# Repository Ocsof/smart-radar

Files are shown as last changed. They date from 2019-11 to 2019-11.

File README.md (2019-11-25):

This is an embedded system implementing a smart radar for seeking and tracking objects.

It's made of a sonar S mounted on a servo-motor M that allows 0-180° rotation, a pir P,  two red leds LD e LA, 
three buttons Tm1, Tm2,Tm3, a potentiometer Pot, placed as shown:

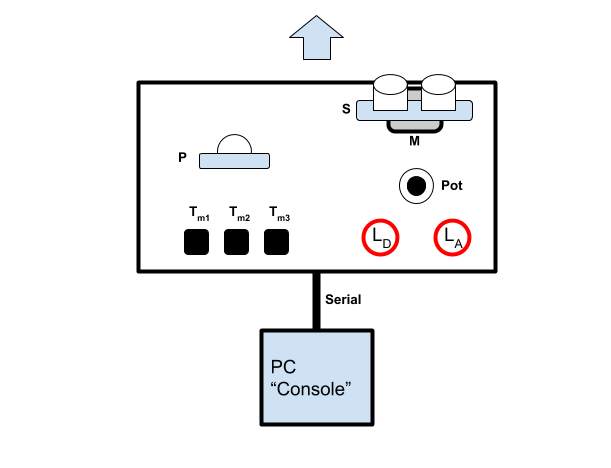
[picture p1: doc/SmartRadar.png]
alternativetext


The system is connected via serial asynchronous communication to PC, where a Java application, called "ConsoleFX" represents the other end of the system.

Features

The system has three modes : single, manual and auto. 

In single mode, the system waits for pir P to detect movement. After this event, the radar execute a full sweep, sending data to the Console. 
Sweep consists in detecting and measuring distance of objects within a 180° angle, divided in 16 slices. 
In a single sweep, the servo stops itself at each of the 16 positions - from first one to last one - and detects objects.
The speed of the sweep can be adjusted by the user from the Console or by turning the potentiometer P.  
The results will be displayed on the console. Every time an ojects is detected, led LD will be turned on.

In manual mode, the radar is driven via Console, thus the user can move it with arrow keys (left or right). 
The current position in degrees and distance of objects (if detected) will be displayed on the Console as well.

In auto mode the system constantly makes full sweeps, updating on Console every measurement.
Speed can be tuned as in single mode. 
If the radar reveal an object less than 40cm far, the system enters an alarm status, notified on Console, and with blinking of led LA. 
If in the next sweep conditions are no longer met, then the system exits alarm status.
Whenever the radar detects an object less than 20cm far, then it enters tracking mode: the sweep pause and the object distance is constantly tracked. 
As soon as the object is no longer detected within 20cm, the system exits tracking mode and goes on with the sweeping activity.

Modes (single, manual, auto) can be selected on the Console and with buttons: Tm1 selects single, Tm2 manual, Tm3 auto. 

On startup the selected mode is manual.

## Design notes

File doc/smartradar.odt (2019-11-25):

[Sistemi Embedded e IoT - a.a. 2019-2020]

Progetto #2 - Smart Radar

Alpi Davide 831238

Foschini Francesco 826200

Penazzi Paolo 825618

IMPORTANTE: Nella classe “SmartConsole” dell’applicazione Java cambiare la stringa passata alla “new SerialCommChannel()” in base al nome della propria porta seriale.

Esempio su un pc Apple: "/dev/cu.usbmodem1421"

Esempio su un pc Windows: "COM10"

# Descrizione soluzione

## Model

Abbiamo sviluppato per prima cosa le classi di model, rappresentanti ogni componente fisico (pulsanti, led, potenziometro, servo, sonar, pir).

Tutti questi elementi sono incapsulati dentro la classe Radar.

Tale classe contiene inoltre importanti informazioni sullo stato del sistema:

- la modalità {SINGLE, MANUAL, AUTO}
- la velocità {ULTRASLOW, SLOW, NORMAL, FAST}
- i comandi ricevuti {MOVE_LEFT, MOVE_RIGHT, MODE_SINGLE, MODE_MANUAL, MODE_AUTO, SPEED_ULTRASLOW, SPEED_NORMAL, SPEED_FAST}
- lo stato di allarme
- l’ultima misurazione effettuata

## Tasks

Ogni task possiede un puntatore alla classe Radar, che viene istanziata nel setup.

La scelta del periodo base dello scheduler possedeva 2 vincoli principali. Il primo è che doveva essere sufficientemente alto da permettere un timeout ragionevole alla funzione pulseIn() del sonar. Il secondo è che doveva essere sufficientemente breve per non perdersi pressioni di pulsanti (gestiti sempre tramite task, quindi polling).

Abbiamo optato per 50ms, ampiamente sufficienti per misurare diversi metri di distanza col sonar e tali da non perdere mai eventi di pressione.
I nostri pulsanti rimbalzano fino a 100ms, nel caso se ne possiedano di più precisi, si può ridurre tranquillamente il periodo base a 25ms.

I task sono:

- 3 per il polling sui pulsanti, che inviano al Radar il messaggio relativo al cambio di modalità quando rilevano una pressione. input
- 1 per il blinking dei led di allarme e di rilevazione. output
- 1 per la misurazione della distanza dal sonar input
- 1 per la lettura della seriale input
- 1 per la scrittura sulla seriale output
- 1 task per ogni modalità, che si occupano del movimento del servo e delle logiche proprie di ogni modalità. output

I task di input sono schedulati prima dei task di movimento del servo, per evitare comportamenti indesiderati. Così abbiamo anche il vantaggio che si misura col sonar prima di muovere il servo, evitando quindi errori fisici derivati da letture in movimento.

Alcuni task all’interno del proprio tick reimpostano dinamicamente il proprio periodo, in base alla “speed” del Radar. Ad ogni valore dell’enum Speed è associato infatti un intero rappresentante il periodo in ms.

Tenendo come riferimento per uno sweep completo Tmin = 2s e Tmax=10s, e considerando che le posizioni sono 16, abbiamo calcolato i seguenti periodi:

ULTRASLOW = 600ms (Tsweep = 600 * 16 = 9600ms)

SLOW = 450ms (Tsweep = 450 * 16 = 7200ms)

NORMAL = 300ms (Tsweep = 300 * 16 = 4800ms)

FAST = 150ms (Tsweep = 150 * 16 = 2400ms)

## Console

La console si occupa di visualizzare tutti i messaggi ricevuti da arduino e di attivare/disattivare lo stato di allarme (contorno rosso sulla text area).

Sono presenti poi pulsanti autoesplicativi che permettono di selezionare modalità e velocità del radar.

Con freccia sx e freccia dx da tastiera è possibile inoltre pilotare il radar in modalità manual.

Siamo a conoscenza di un bug per il quale a volte si freeza la text area e non si aggiorna più con i messaggi che arrivano. In tal caso chiudere e riaprire l’applicazione.

# Note sulle specifiche

In modalità single, il sistema effettua una singola scansione e va in modalità risparmio energetico (sleep mode). Si risveglia solo quando viene rilevato movimento dal pir P. A fronte di questo evento, il sistema esegue una scansione.

Notare che mentre il sistema è in sleep, l’unico modo per svegliarlo è tramite il pir.

Il led LD si accende solo in modalità single quando l’ultima misurazione effettuata ha rilevato un oggetto ad una qualsiasi distanza.

La velocità impostata influisce allo stesso modo sul tempo impiegato per effettuare uno sweep completo in ognuna delle 3 modalità.

## Schema circuito

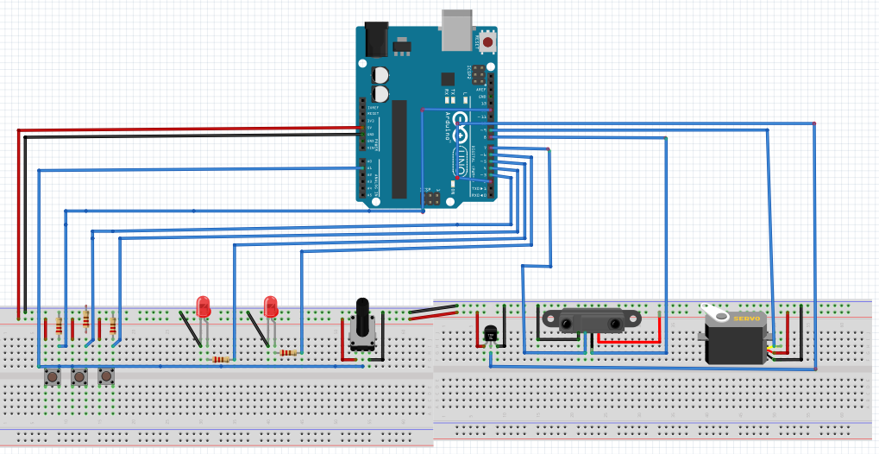
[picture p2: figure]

# Diagrammi macchine a stati finiti dei singoli task

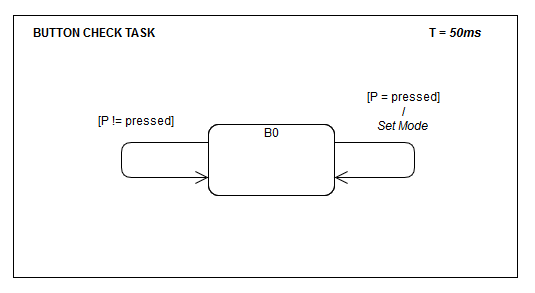
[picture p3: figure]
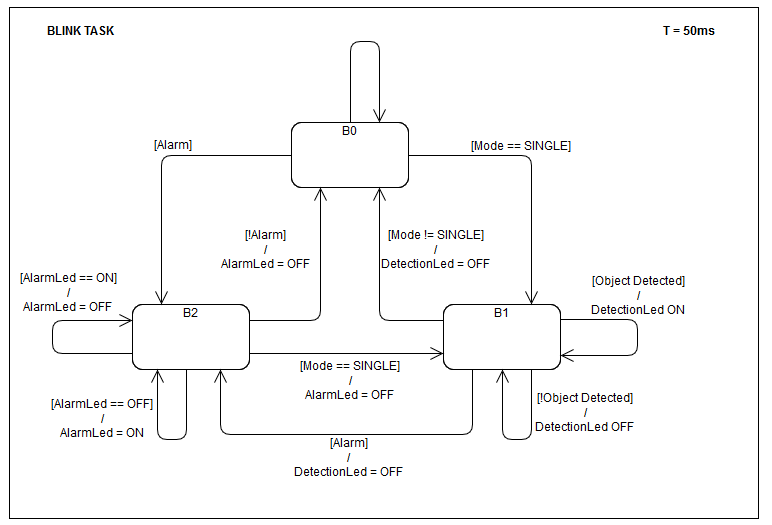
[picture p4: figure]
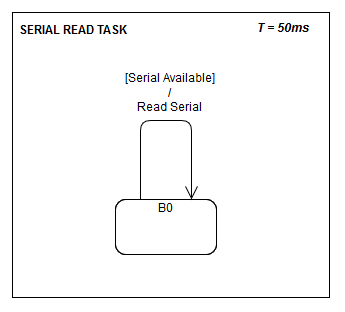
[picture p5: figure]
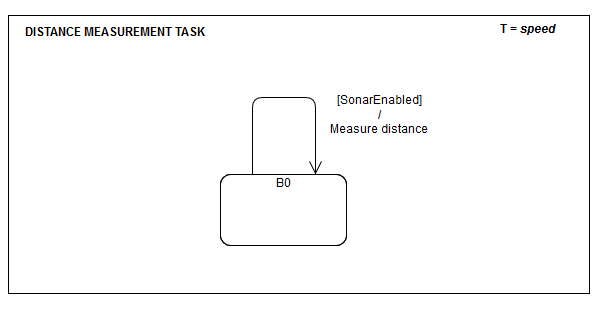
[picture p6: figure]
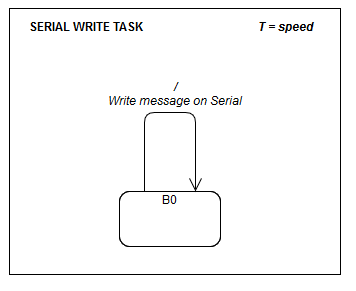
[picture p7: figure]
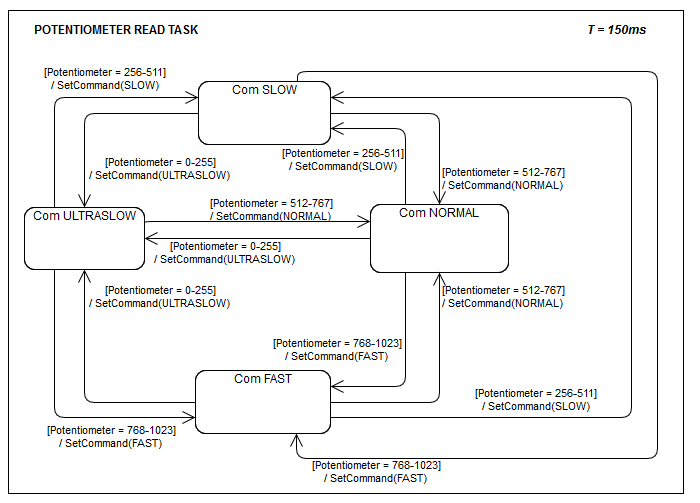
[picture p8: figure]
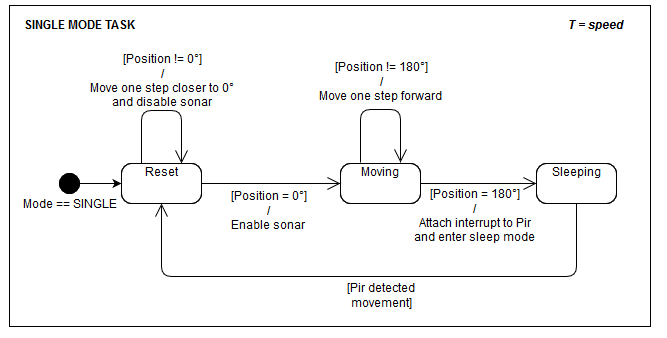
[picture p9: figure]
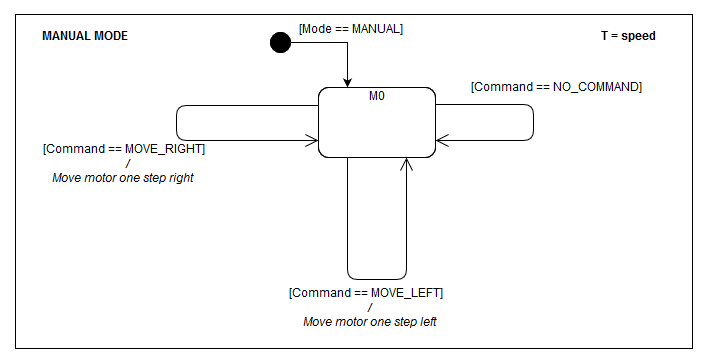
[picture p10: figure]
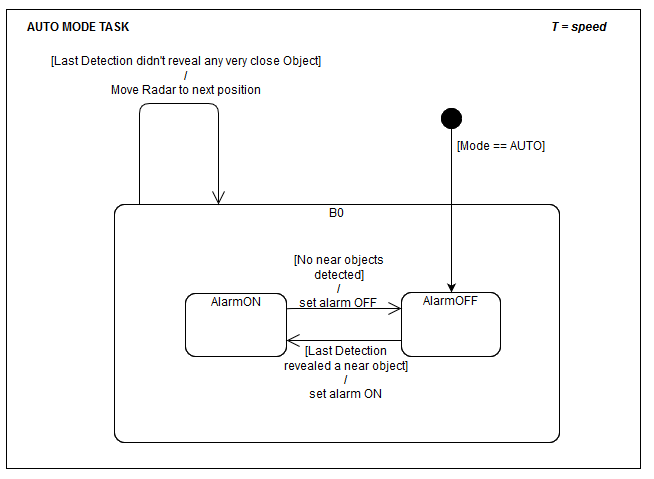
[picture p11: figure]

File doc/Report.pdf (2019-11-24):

## [Sistemi Embedded e IoT - a.a. 2019-2020]

# Progetto #2 - Smart Radar

Alpi Davide 831238
Foschini Francesco 826200
Penazzi Paolo 825618

### Descrizione soluzione

### Model

Abbiamo sviluppato per prima cosa le classi di model, rappresentanti ogni componente fisico (pulsanti, led, potenziometro, servo, sonar, pir).
Tutti questi elementi sono incapsulati dentro la classe Radar.
Tale classe contiene inoltre importanti informazioni sullo stato del sistema:
- la modalità {SINGLE, MANUAL, AUTO}
- la velocità {ULTRASLOW, SLOW, NORMAL, FAST}
- i comandi ricevuti {MOVE_LEFT, MOVE_RIGHT, MODE_SINGLE, MODE_MANUAL, MODE_AUTO, SPEED_ULTRASLOW, SPEED_NORMAL, SPEED_FAST}
- lo stato di allarme
- l’ultima misurazione effettuata

### Tasks

Ogni task possiede un puntatore alla classe Radar, che viene istanziata nel setup. La scelta del periodo base dello scheduler possedeva 2 vincoli principali. Il primo è che doveva essere sufficientemente alto da permettere un timeout ragionevole alla funzione pulseIn() del sonar. Il secondo è che doveva essere sufficientemente breve per non perdersi pressioni di pulsanti (gestiti sempre tramite task, quindi polling). Abbiamo optato per 50ms, ampiamente sufficienti per misurare diversi metri di distanza col sonar e tali da non perdere mai eventi di pressione.
I nostri pulsanti rimbalzano fino a 100ms, nel caso se ne possiedano di più precisi, si può ridurre tranquillamente il periodo base a 25ms.

I task sono:
- 3 per il polling sui pulsanti, che inviano al Radar il messaggio relativo al
cambio di modalità quando rilevano una pressione. | input
- 1 per il blinking dei led di allarme e di rilevazione. | output
- 1 per la misurazione della distanza dal sonar | input
- 1 per la lettura della seriale | input
- 1 per la scrittura sulla seriale | output
- 1 task per ogni modalità, che si occupano del movimento del servo e delle
logiche proprie di ogni modalità. | output

I task di input sono schedulati prima dei task di movimento del servo, per evitare comportamenti indesiderati. Così abbiamo anche il vantaggio che si misura col sonar prima di muovere il servo, evitando quindi errori fisici derivati da letture in movimento.
Alcuni task all’interno del proprio tick reimpostano dinamicamente il proprio periodo, in base alla “speed” del Radar. Ad ogni valore dell’enum Speed è associato infatti un intero rappresentante il periodo in ms.
Tenendo come riferimento per uno sweep completo Tmin = 2s e Tmax=10s, e considerando che le posizioni sono 16, abbiamo calcolato i seguenti periodi: ULTRASLOW = 600ms (Tsweep = 600 * 16 = 9600ms)
SLOW = 450ms (Tsweep = 450 * 16 = 7200ms)
NORMAL = 300ms (Tsweep = 300 * 16 = 4800ms)
FAST = 150ms (Tsweep = 150 * 16 = 2400ms)

### Console

La console si occupa di visualizzare tutti i messaggi ricevuti da arduino e di attivare/disattivare lo stato di allarme (contorno rosso sulla text area).
Sono presenti poi pulsanti autoesplicativi che permettono di selezionare modalità e velocità del radar.
Con freccia sx e freccia dx da tastiera è possibile inoltre pilotare il radar in modalità manual.
Siamo a conoscenza di un bug per il quale a volte si freeza la text area e non si aggiorna più con i messaggi che arrivano. In tal caso chiudere e riaprire l’applicazione.

## Note sulle specifiche

In modalità single, il sistema effettua una singola scansione e va in modalità risparmio energetico (sleep mode). Si risveglia solo quando viene rilevato movimento dal pir P. A fronte di questo evento, il sistema esegue una scansione.
Notare che mentre il sistema è in sleep, l’unico modo per svegliarlo è tramite il pir.

Il led LD si accende solo in modalità single quando l’ultima misurazione effettuata ha rilevato un oggetto ad una qualsiasi distanza.

La velocità impostata influisce allo stesso modo sul tempo impiegato per effettuare uno sweep completo in ognuna delle 3 modalità.
Schema circuito

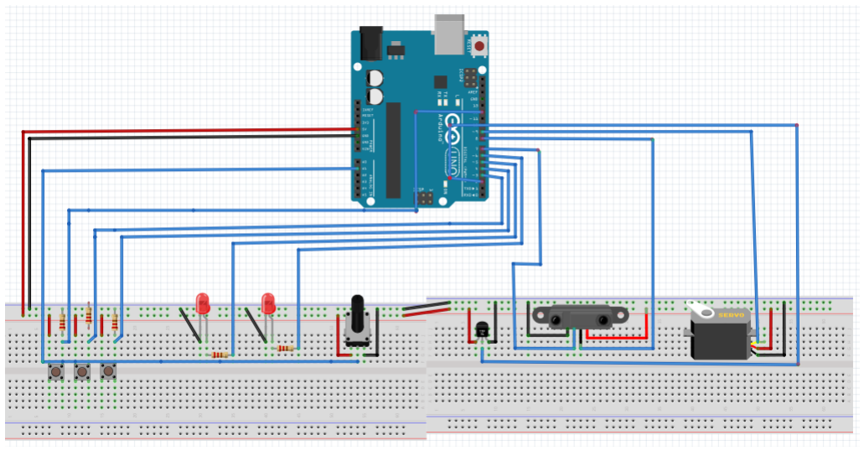
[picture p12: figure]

## Diagrammi macchine a stati finiti dei singoli task

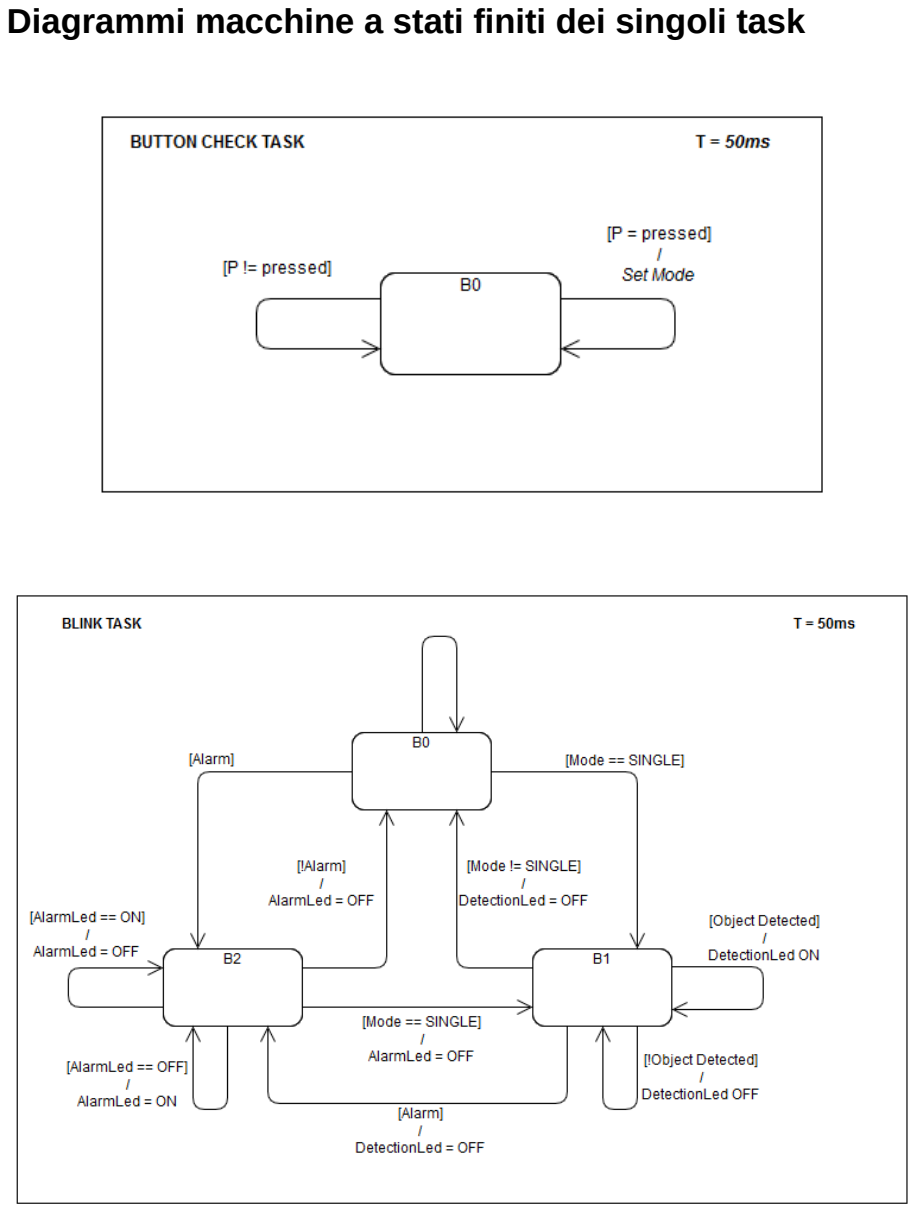
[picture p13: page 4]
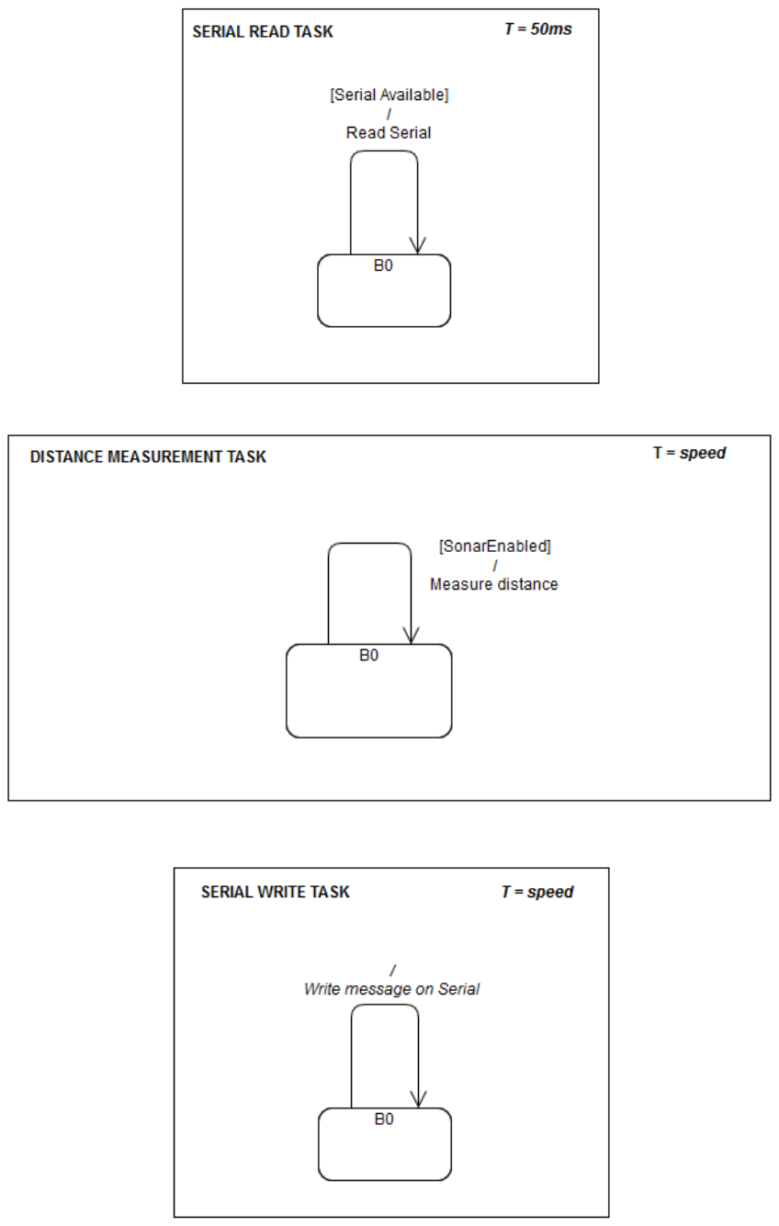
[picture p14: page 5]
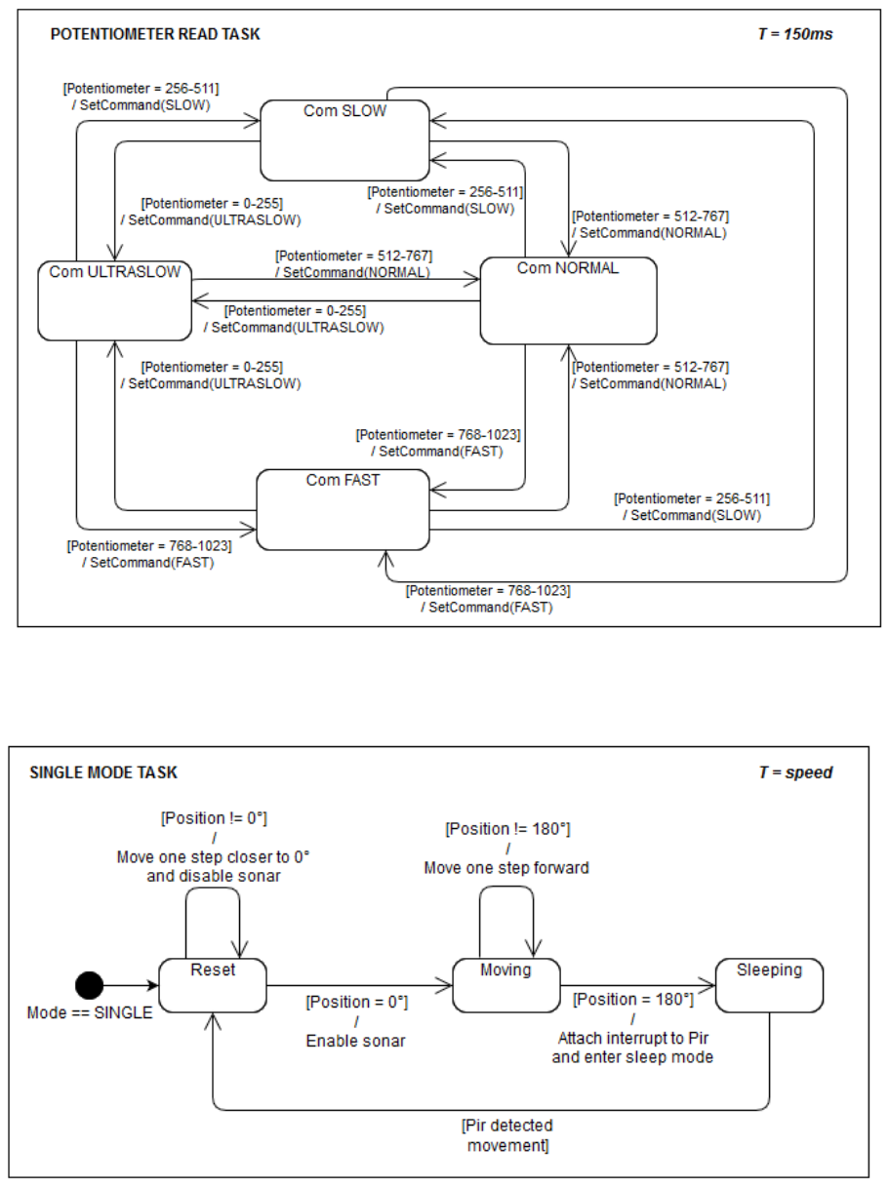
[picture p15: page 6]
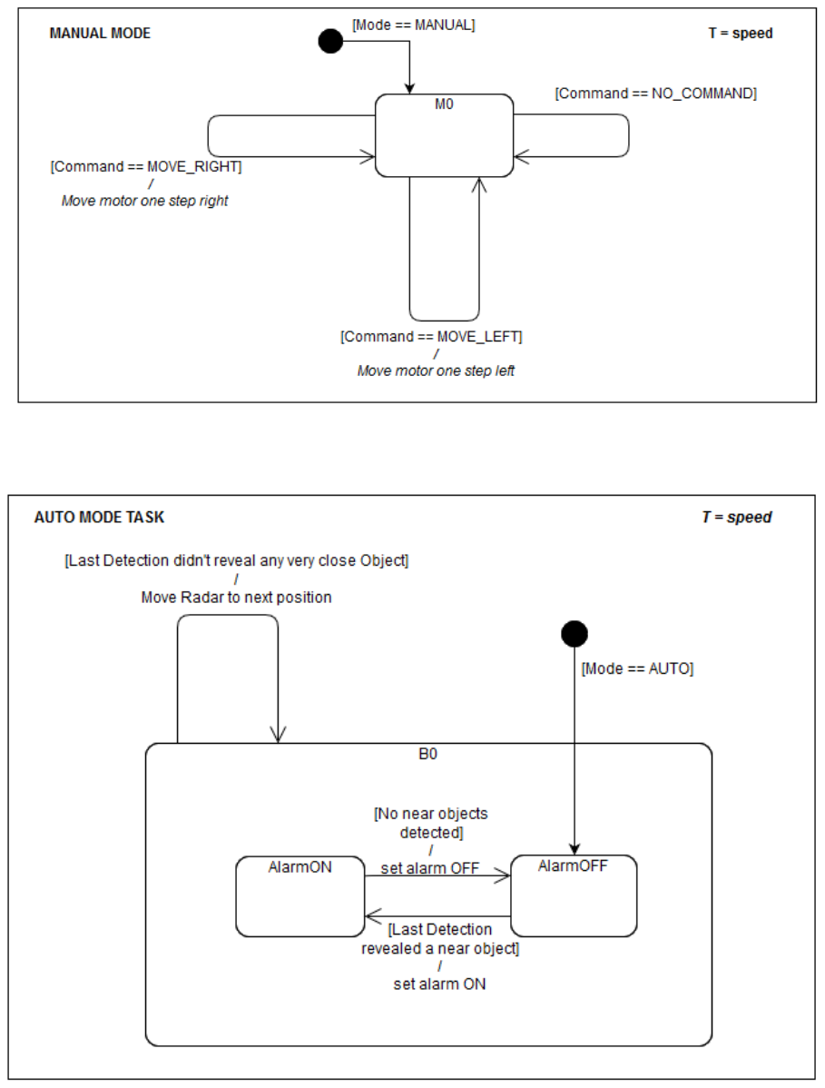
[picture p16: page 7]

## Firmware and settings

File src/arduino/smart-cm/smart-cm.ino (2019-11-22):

#include "Scheduler.h"
#include "BlinkTask.h"
#include "ButtonCheckTask.h"
#include "DistanceMeasurementTask.h"
#include "AutoModeTask.h"
#include "SingleModeTask.h"
#include "ManualModeTask.h"
#include "SerialReadTask.h"
#include "SerialWriteTask.h"
#include "PotentiometerReadTask.h"

Scheduler sched;
Radar* SmartRadar;

void setup(){
  Serial.begin(9600); 
  SmartRadar = new Radar();
  sched.init(50);
 
  Task* t0 = new ButtonCheckTask(SmartRadar, SmartRadar->getButtonS(), Command::MODE_SINGLE);
  t0->init(50);

  Task* t1 = new ButtonCheckTask(SmartRadar, SmartRadar->getButtonM(), Command::MODE_MANUAL);
  t1->init(50);

  Task* t2 = new ButtonCheckTask(SmartRadar, SmartRadar->getButtonA(), Command::MODE_AUTO);
  t2->init(50);

  Task* t3 = new BlinkTask(SmartRadar);
  t3->init(50);

  Task* t4 = new DistanceMeasurementTask(SmartRadar);
  t4->init(150);

  Task* t5 = new PotentiometerReadTask(SmartRadar);
  t5->init(150);

  Task* t6 = new SerialWriteTask(SmartRadar);
  t6->init(150);

  Task* t7 = new SerialReadTask(SmartRadar);
  t7->init(50);

  Task* t8 = new SingleModeTask(SmartRadar);
  t8->init(150);

  Task* t9 = new ManualModeTask(SmartRadar);
  t9->init(150);

  Task* t10 = new AutoModeTask(SmartRadar);
  t10->init(150);
  
  sched.addTask(t0);
  sched.addTask(t1);
  sched.addTask(t2);
  sched.addTask(t3);
  sched.addTask(t4);
  sched.addTask(t5);
  sched.addTask(t6);
  sched.addTask(t7);
  sched.addTask(t8);
  sched.addTask(t9);
  sched.addTask(t10);
}

void loop(){
  sched.schedule();
}

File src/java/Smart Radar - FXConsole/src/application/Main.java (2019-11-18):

package application;
	
import javafx.application.Application;
import javafx.stage.Stage;
import javafx.scene.Scene;
import javafx.scene.layout.AnchorPane;
import javafx.fxml.FXMLLoader;


public class Main extends Application {
	
	
	@Override
	public void start(Stage primaryStage) {
		try {
			AnchorPane root = (AnchorPane)FXMLLoader.load(getClass().getResource("Sample.fxml"));
			Scene scene = new Scene(root,1200,800);
			scene.getStylesheets().add(getClass().getResource("application.css").toExternalForm());
			primaryStage.setScene(scene);
			primaryStage.show();
		} catch(Exception e) {
			e.printStackTrace();
		}
	}
	
	public static void main(String[] args) {
		launch(args);
	}
}

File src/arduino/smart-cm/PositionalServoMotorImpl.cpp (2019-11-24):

#include "PositionalServoMotorImpl.h"
#include "Arduino.h"

PositionalServoMotorImpl::PositionalServoMotorImpl(int pin, int numOfPositions){
  this->on();
  this->pin = pin; 
  this->currentPosition = 0; 
  this->motor.write(this->convertPosition(0));
  this->target = 0;
  this->numOfPositions = numOfPositions;
  this->step = 180 / (this->numOfPositions - 1); // 180 / number of steps
} 

void PositionalServoMotorImpl::on(){
  motor.attach(pin);    
}

int PositionalServoMotorImpl::getCurrentPosition(){
  return this->currentPosition / step;
}

void PositionalServoMotorImpl::off(){
  motor.detach();    
}

void PositionalServoMotorImpl::incrementTarget(){
  if(this->target <= 180-step){
     this->target += step;
  }
}

void PositionalServoMotorImpl::decrementTarget(){
  if(this->target >= step) {
     this->target -= step;
  }
}

void PositionalServoMotorImpl::stepForwardTarget(){
  if(this->currentPosition != this->target){
    if(this->currentPosition > this->target){
      this->currentPosition -= step;
    }
    else{
      this->currentPosition += step;
    }
    this->motor.write(this->convertPosition(this->currentPosition));
  } 
}

void PositionalServoMotorImpl::alignTarget(){
  this->target = this->currentPosition;
}

int PositionalServoMotorImpl::getNumOfPositions(){
  return this->numOfPositions;
}

int PositionalServoMotorImpl::getStepValue(){
  return this->step;
}

int PositionalServoMotorImpl::convertPosition(int position){
  return position*10 + 544;
};

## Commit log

2019-11-06 Create repo and add fritzing diagram
    [smart_sonar.fzz]
2019-11-18 Fix no member bug and typos
    [AutoModeTask.cpp, ManualModeTask.cpp]
2019-11-24 design of .fzz modify
    [smart_sonar.fzz]
2019-11-24 Version 1.3
    [Schema_circuito.fzz]
